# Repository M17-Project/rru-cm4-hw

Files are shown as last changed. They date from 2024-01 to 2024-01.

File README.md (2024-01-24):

[][cc-by-nc-sa]

# rru-cm4-hw
Remote Radio Unit - interface board

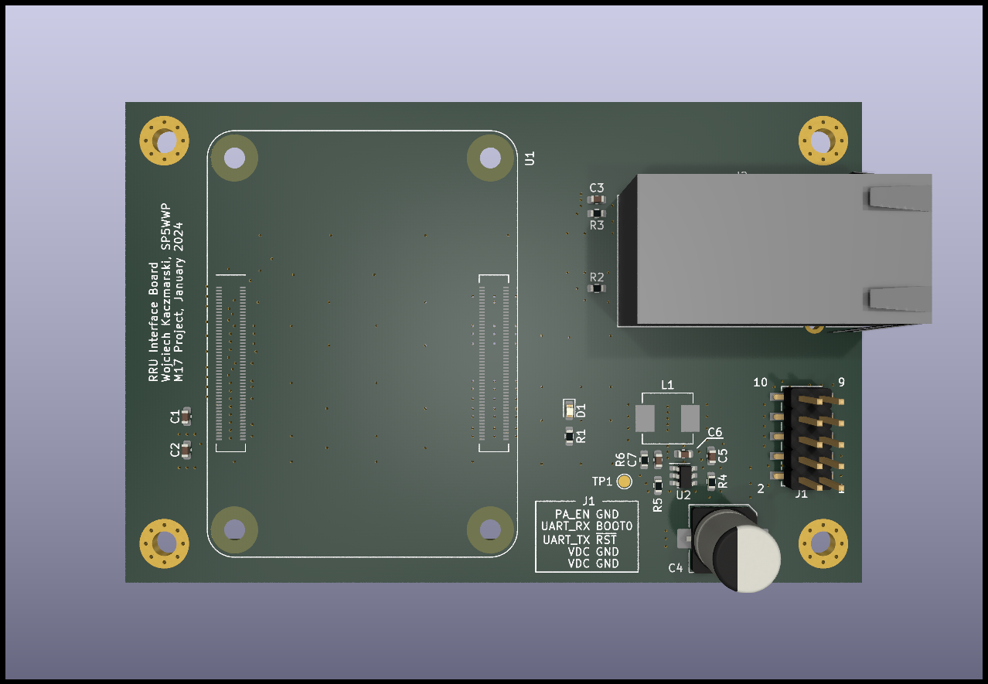
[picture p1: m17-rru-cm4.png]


## License
This work is licensed under a
[Creative Commons Attribution-NonCommercial-ShareAlike 4.0 International License][cc-by-nc-sa].

[][cc-by-nc-sa]

[cc-by-nc-sa]: http://creativecommons.org/licenses/by-nc-sa/4.0/
[cc-by-nc-sa-image]: https://licensebuttons.net/l/by-nc-sa/4.0/88x31.png
[cc-by-nc-sa-shield]: https://img.shields.io/badge/License-CC%20BY--NC--SA%204.0-lightgrey.svg

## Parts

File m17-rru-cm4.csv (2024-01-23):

Reference | Value | Footprint | Datasheet | MPN | PN | Qty
C1-C3, C5, C6 | 100n | Capacitor_SMD:C_0603_1608Metric | ~ | C0603C104M5RAC7411 | C0603C104M5RAC7411 | 5
C4 | 100u/50V | Capacitor_SMD:CP_Elec_8x10.5 | ~ | 50SEV100M8X10.5 | 50SEV100M8X10.5 | 1
C7 | 22u/6.3V | Capacitor_SMD:C_0603_1608Metric | ~ | GRM188R60J226MEA0J | GRM188R60J226MEA0J | 1
D1 | LED GRN | LED_SMD:LED_0603_1608Metric | ~ | 604-APT1608SECK-AMT | 604-APT1608SECK-AMT | 1
H1-H4 | MountingHole_Pad | MountingHole:MountingHole_3.2mm_M3_Pad_Via | ~ | - | - | 4
J1 | Conn_02x05_Odd_Even | Connector_PinHeader_2.54mm:PinHeader_2x05_P2.54mm_Vertical_SMD | ~ | 649-1012938391001ALF | 649-1012938391001ALF | 1
J2 | RJ45_JK0654219 | Connector_RJ:RJ45_Pulse_JK0654219NL_Horizontal | https://media.digikey.com/pdf/Data%20Sheets/Pulse%20PDFs/JK%20Series.pdf | 673-JK0654219NL | 673-JK0654219NL | 1
L1 | 10u | Inductor_SMD:L_Vishay_IHLP-2525 | ~ | IHLP2525BDER100M01 | IHLP2525BDER100M01 | 1
R1-R3 | 470R | Resistor_SMD:R_0603_1608Metric | ~ | 71-CRCW0603J-470-E3 | 71-CRCW0603J-470-E3 | 3
R4 | 100k | Resistor_SMD:R_0603_1608Metric | ~ | CRCW0603100KFKEAC | CRCW0603100KFKEAC | 1
R5 | 24k | Resistor_SMD:R_0603_1608Metric | ~ | CRCW060324K0FKEAC | CRCW060324K0FKEAC | 1
R6 | 126k | Resistor_SMD:R_0603_1608Metric | ~ | TNPW0603126KBEEA | TNPW0603126KBEEA | 1
TP1 | TP | TestPoint:TestPoint_Pad_D1.5mm | ~ | - | - | 1
U1 | Compute Module 4 | RPi:Raspberry-Pi-4-Compute-Module |  | 798-DF40HC30100DS451 | 798-DF40HC30100DS451 | 1
U2 | TP6841 | Package_TO_SOT_SMD:SOT-23-6 |  | TP6841S6-A | TP6841S6-A | 1

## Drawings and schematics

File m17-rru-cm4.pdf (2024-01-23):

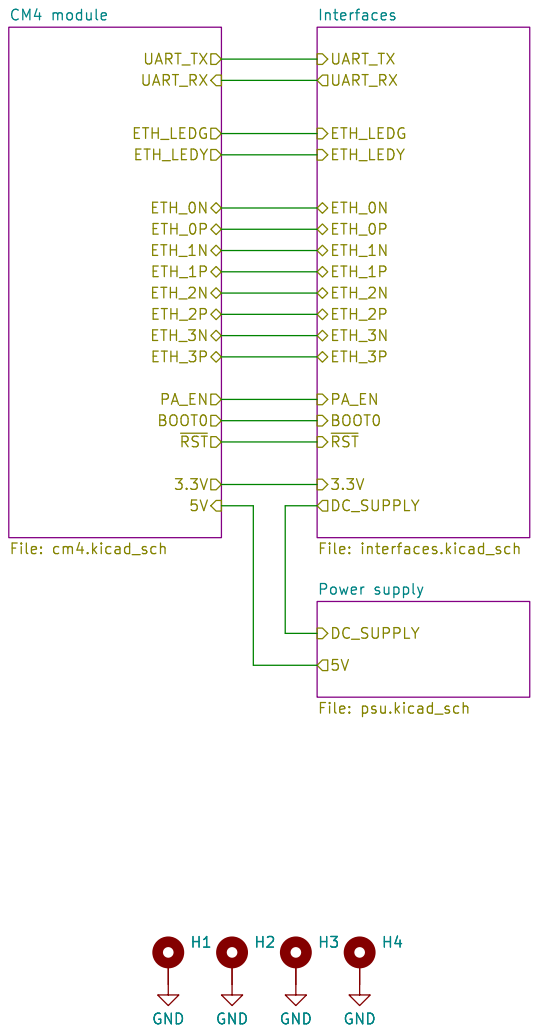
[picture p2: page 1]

Interfaces File: interfaces.kicad_sch ~{RST} BOOT0 ETH_0N
5V UART_TX UART_RX

Power supply File: psu.kicad_sch DC_SUPPLY

Id: 1/4 Title: RRU CM4 board

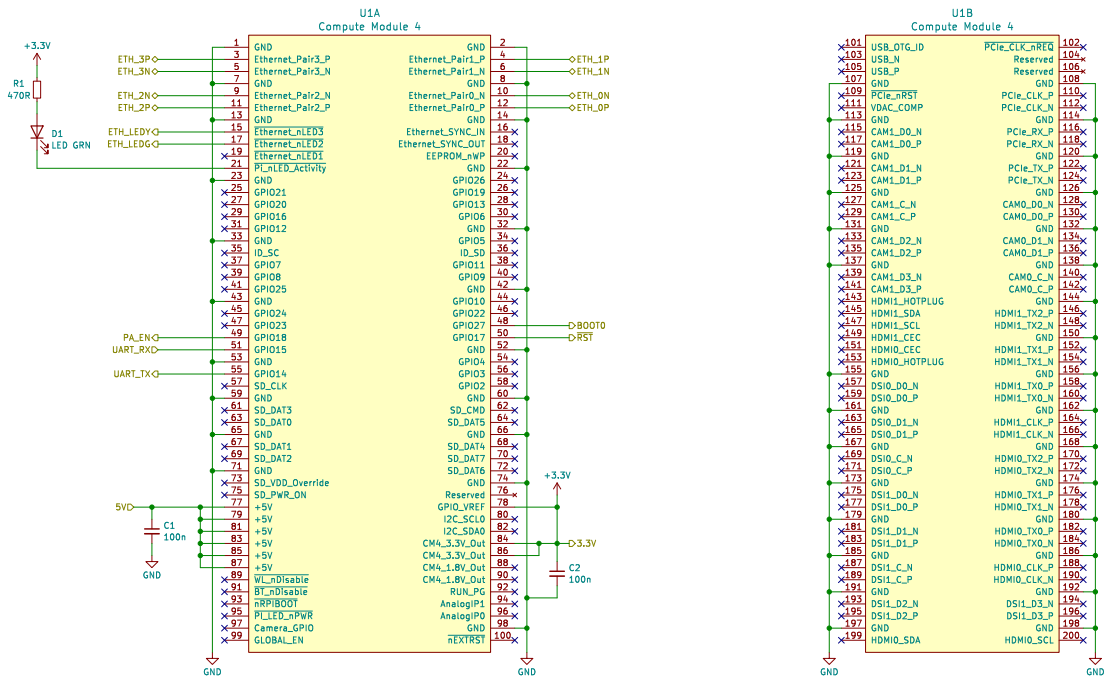
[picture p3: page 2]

Id: 2/4 Title: RRU CM4 board

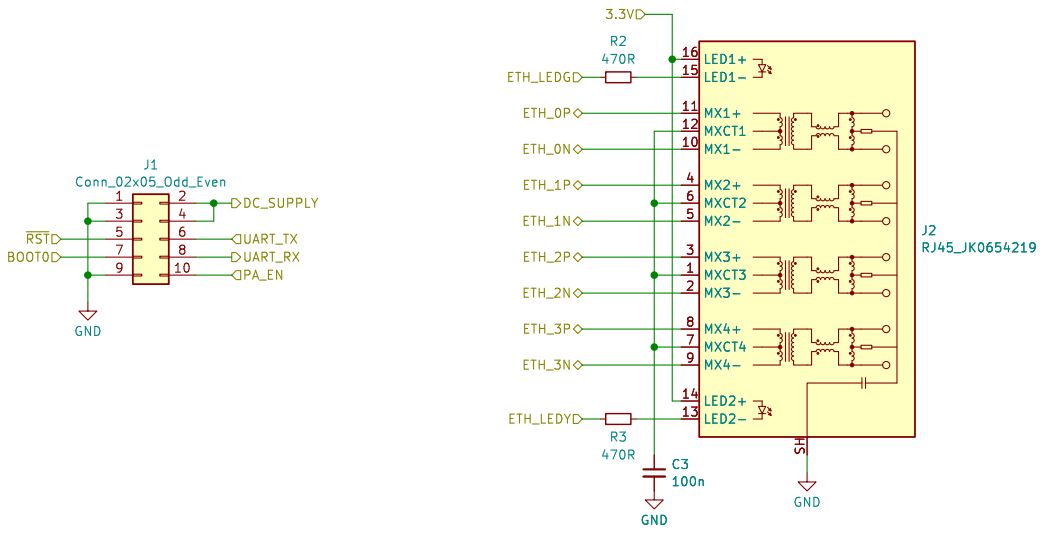
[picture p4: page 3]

Id: 3/4 Title: RRU CM4 board

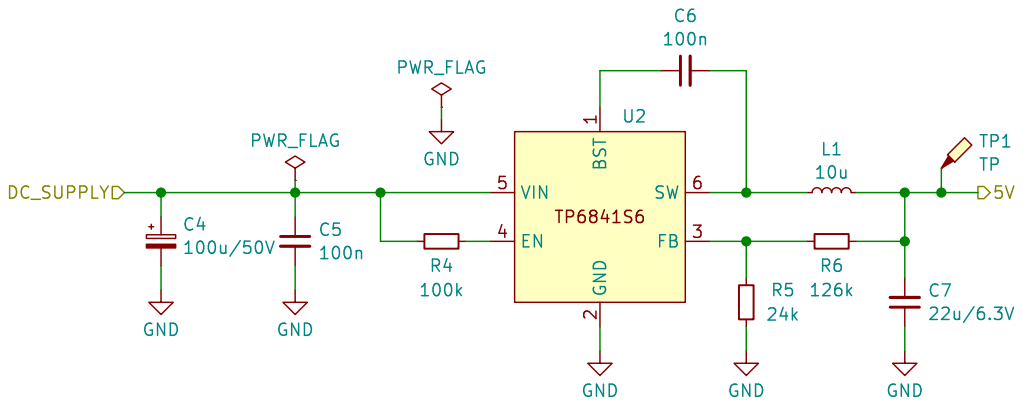
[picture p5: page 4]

2 FB 3 EN 4 VIN 5 SW 6 U2 C5

Id: 4/4 Title: RRU CM4 board

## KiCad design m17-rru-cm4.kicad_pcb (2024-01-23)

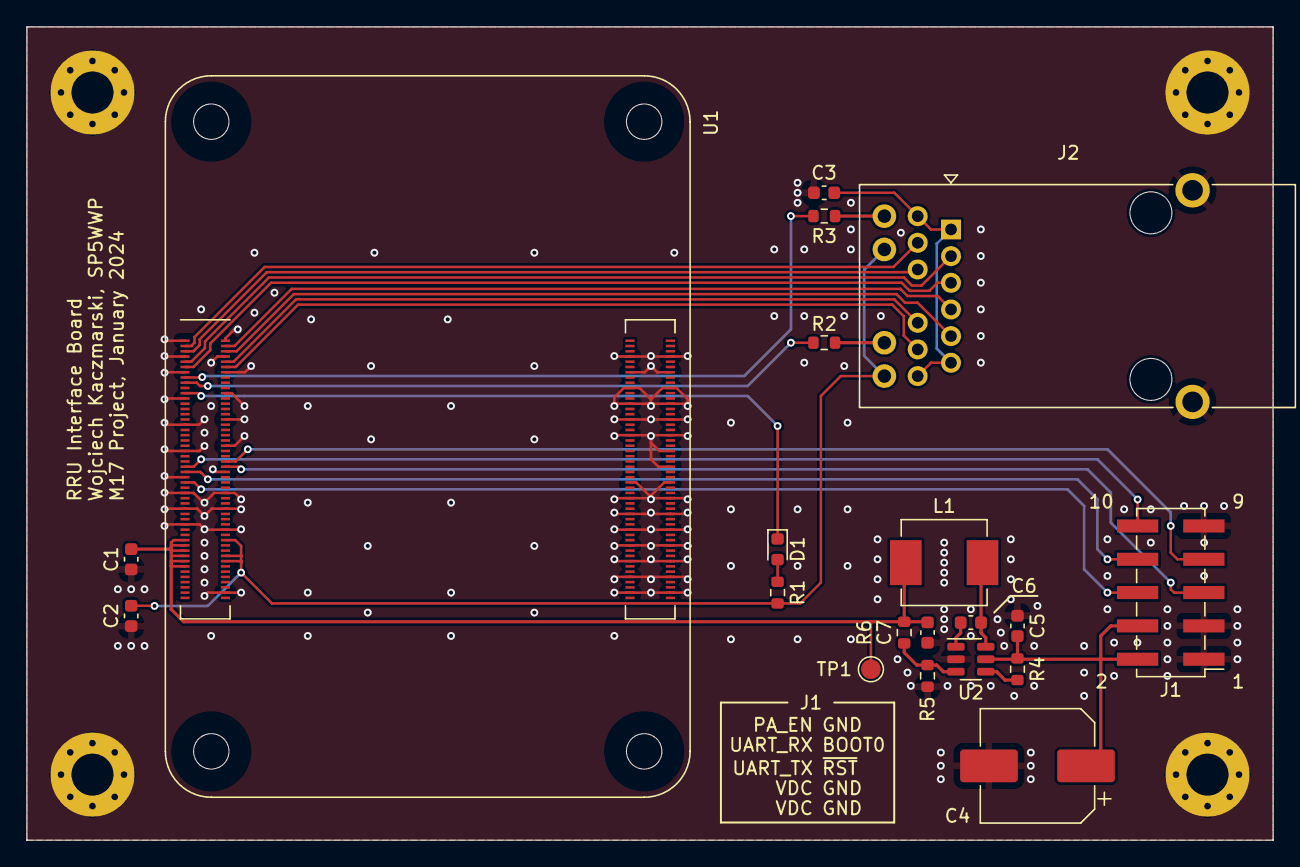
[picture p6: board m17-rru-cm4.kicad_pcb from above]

Board: 2 copper layers, 95.0 x 62.0 mm, 24 parts (0 on the bottom side), 28 nets.

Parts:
C1, C2, C3, C5, C6: 100n; C_0603_1608Metric
C4: 100u/50V; CP_Elec_8x10.5
C7: 22u/6.3V; C_0603_1608Metric
D1: LED GRN; LED_0603_1608Metric
H1, H2, H3, H4: MountingHole_Pad; MountingHole_3.2mm_M3_Pad_Via
J1: Conn_02x05_Odd_Even; PinHeader_2x05_P2.54mm_Vertical_SMD
J2: RJ45_JK0654219; RJ45_Pulse_JK0654219NL_Horizontal
L1: 10u; L_Vishay_IHLP-2525
R1, R2, R3: 470R; R_0603_1608Metric
R4: 100k; R_0603_1608Metric
R5: 24k; R_0603_1608Metric
R6: 126k; R_0603_1608Metric
TP1: TP; TestPoint_Pad_D1.5mm
U1: Compute Module 4; Raspberry-Pi-4-Compute-Module
U2: TP6841; SOT-23-6

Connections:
+3.3V: C2.1, J2.14 (LED2+), J2.16 (LED1+), R1.1, U1.78 (GPIO_VREF), U1.84 (CM4_3.3V_Out), U1.86 (CM4_3.3V_Out)
/CM4 module/5V: C1.1, C7.2, L1.2, R6.2, TP1.1, U1.77 (+5V), U1.79 (+5V), U1.81 (+5V), U1.83 (+5V), U1.85 (+5V), U1.87 (+5V)
/CM4 module/BOOT0: J1.7, U1.48 (GPIO27)
/CM4 module/ETH_0N: J2.10 (MX1-), U1.10 (Ethernet_Pair0_N)
/CM4 module/ETH_0P: J2.11 (MX1+), U1.12 (Ethernet_Pair0_P)
/CM4 module/ETH_1N: J2.5 (MX2-), U1.6 (Ethernet_Pair1_N)
/CM4 module/ETH_1P: J2.4 (MX2+), U1.4 (Ethernet_Pair1_P)
/CM4 module/ETH_2N: J2.2 (MX3-), U1.9 (Ethernet_Pair2_N)
/CM4 module/ETH_2P: J2.3 (MX3+), U1.11 (Ethernet_Pair2_P)
/CM4 module/ETH_3N: J2.9 (MX4-), U1.5 (Ethernet_Pair3_N)
/CM4 module/ETH_3P: J2.8 (MX4+), U1.3 (Ethernet_Pair3_P)
/CM4 module/ETH_LEDG: R2.1, U1.17 (~Ethernet_nLED2)
/CM4 module/ETH_LEDY: R3.1, U1.15 (~Ethernet_nLED3)
/CM4 module/PA_EN: J1.10, U1.49 (GPIO18)
/CM4 module/UART_RX: J1.8, U1.51 (GPIO15)
/CM4 module/UART_TX: J1.6, U1.55 (GPIO14)
/CM4 module/~RST: J1.5, U1.50 (GPIO17)
/Interfaces/DC_SUPPLY: C4.1, C5.1, J1.2, J1.4, R4.1, U2.5 (VIN)
GND: C1.2, C2.2, C3.2, C4.2, C5.2, C7.1, H1.1, H2.1, H3.1, H4.1, J1.1, J1.3, J1.9, J2.SH, R5.2, U1.1 (GND), U1.2 (GND), U1.7 (GND), U1.8 (GND), U1.13 (GND), U1.14 (GND), U1.22 (GND), U1.23 (GND), U1.32 (GND), U1.33 (GND), U1.42 (GND), U1.43 (GND), U1.52 (GND), U1.53 (GND), U1.59 (GND), U1.60 (GND), U1.65 (GND), U1.66 (GND), U1.71 (GND), U1.74 (GND), U1.98 (GND), U1.107 (GND), U1.108 (GND), U1.113 (GND), U1.114 (GND), U1.119 (GND), U1.120 (GND), U1.125 (GND), U1.126 (GND), U1.131 (GND), U1.132 (GND), U1.137 (GND), U1.138 (GND), U1.144 (GND), U1.150 (GND), U1.155 (GND), U1.156 (GND), U1.161 (GND), U1.162 (GND), U1.167 (GND), U1.168 (GND), U1.173 (GND), U1.174 (GND), U1.179 (GND), U1.180 (GND), U1.185 (GND), U1.186 (GND), U1.191 (GND), U1.192 (GND), U1.197 (GND), U1.198 (GND), U2.2 (GND)
unnamed: D1.2 (A), R1.2
unnamed: D1.1 (K), U1.21 (~Pi_nLED_Activity)
unnamed: J2.15 (LED1-), R2.2
unnamed: J2.13 (LED2-), R3.2
unnamed: C3.1, J2.1 (MXCT3), J2.6 (MXCT2), J2.7 (MXCT4), J2.12 (MXCT1)
unnamed: C6.1, U2.1 (BST)
unnamed: R4.2, U2.4 (EN)
unnamed: R5.1, R6.1, U2.3 (FB)
unnamed: C6.2, L1.1, U2.6 (SW)

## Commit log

2024-01-22 PN update, BOM
    [cm4.kicad_sch, interfaces.kicad_sch, m17-rru-cm4.csv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]
2024-01-22 WIP PCB
    [interfaces.kicad_sch, m17-rru-cm4.kicad_pcb]
2024-01-22 NC pins
    [cm4.kicad_sch]
2024-01-23 WIP PCB layout
    [cm4.kicad_sch, interfaces.kicad_sch, m17-rru-cm4.kicad_pcb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]
2024-01-23 silkscreen update
    [m17-rru-cm4.kicad_pcb]
2024-01-23 BOM update
    [m17-rru-cm4.csv]
2024-01-23 missing comma
    [m17-rru-cm4.kicad_pcb]
2024-01-24 pcb render

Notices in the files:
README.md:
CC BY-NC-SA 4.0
